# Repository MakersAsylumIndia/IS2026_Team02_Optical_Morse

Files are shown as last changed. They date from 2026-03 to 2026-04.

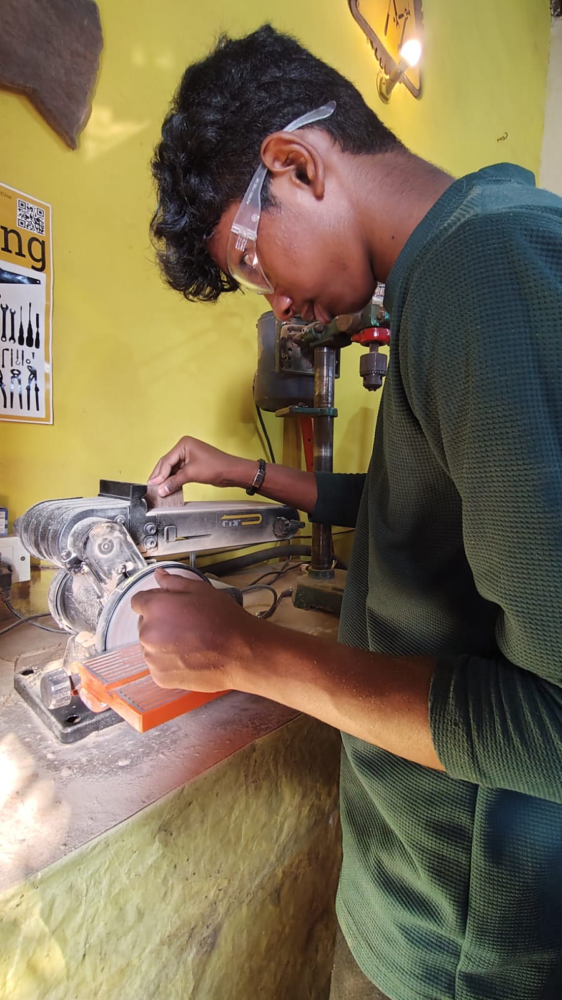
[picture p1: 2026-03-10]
Photos_Videos/Images/IS2026_Team02_Optical_Morse_photo_13.jpeg

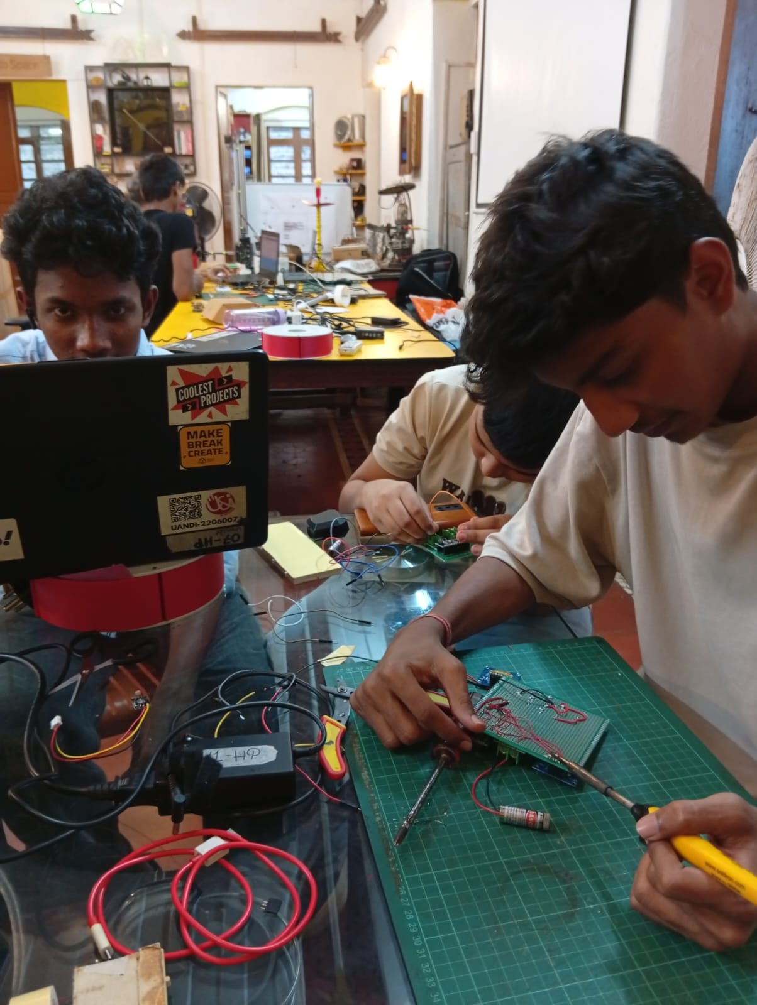
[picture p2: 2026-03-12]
Photos_Videos/Images/IS2026_Team02_Optical_Morse_photo_21.jpeg

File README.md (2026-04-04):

# IS2026 Spring - Team 02 - Optical Morse

We built a device to help communicate using simple lasers and LDR's which is not dependent on WiFi, Bluetooth or other radio technologies. We modulate a laser using morse code, which is interpreted on the receiving side using a LDR. Both sides have identical hardware - Arduino Nano for the microcontroller, a red laser, a LDR, and a mosfet module to modulate the lasers. Text is input via a serial monitor on the Arduino IDE, and on the receiving side it gets printed on the serial monitor as well. We built a simple tripod using 3d printed parts and PVC pipes to hold all the parts. For future iteration, we plan to add an I2C OLED display, some buttons and a 3d printable morse key so that the device can be used independently without attaching a laptop.

## License

Licenses

<a href="LICENSE.md">Open Source Licenses Facts</a>

#### Hardware
CERN Open Hardware License Version 2 - Strongly Reciprocal ([CERN-OHL-S-2.0](https://spdx.org/licenses/CERN-OHL-S-2.0.html)).

#### Software
MIT open source [license](http://opensource.org/licenses/MIT).

#### Documentation:
<br />This work is licensed under a <a rel="license" href="http://creativecommons.org/licenses/by/4.0/">Creative Commons Attribution 4.0 International License</a>.

---
## [OSHWA Certification](https://certification.oshwa.org/list.html)

[OSHW] IN000086 | Certified open source hardware | oshwa.org/cert



---

## 📬 Contact/Team

> _List team members and contact emails or GitHub profiles._<br/>
> [Maker's Asylum](https://github.com/makersasylum)<br/>
> [@anool](https://github.com/Anool)<br/>
> [Aaditya Borhade](https://github.com/Aadityaborhade09)<br/>
> [Afiya](https://github.com/Afiya-gpj)<br/>
> [Prince Kushwaha](https://github.com/PrinceKushwaha09)<br/>
> [suzmak8-cloud](https://github.com/suzmak8-cloud)<br/>
> [Swadhin Kumar Bhoi](https://github.com/swadhinkumarbhoi3-a11y)<br/>
> [Dakshat](https://github.com/dakshatt)<br/>
>
> ---

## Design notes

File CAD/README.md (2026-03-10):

This folder will contain all of your mechanical designs/CAD files.

push test

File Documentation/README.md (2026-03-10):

This folder will contain all of your documentation which includes details of project /instructions/flow diagram files.

testing

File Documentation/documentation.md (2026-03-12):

Optical Morse Communication Project

1\. Introduction

The Optical Morse project is a communication system that sends messages using light signals. In this project, a laser is used as a transmitter and an LDR sensor is used as a receiver. The laser sends Morse code signals, and the receiver detects the light and converts it into readable signals.

2\. Required Components

Arduino Nano

MOSFET module

Laser module

LDR (Light Dependent Resistor)

10k Resistor

Breadboard

Jumper wires

USB cable

3\. Required Components

Laser Transmitter Connection (using MOSFET Module)

Connect Arduino D9 → IN pin of the MOSFET module.

Connect Arduino GND → GND pin of the MOSFET module.

Connect 5V from Arduino → V+ of the MOSFET module.

Connect Arduino GND → V− of the MOSFET module.

Connect Laser positive (+) → OUT+.

Connect Laser negative (−) → OUT−.

LDR Receiver Connection

One leg of LDR → 5V

Other leg of LDR → A0

From the same A0 point → 10k resistor → GND

This forms the voltage divider needed for reading light.

4\. Working Principle (Optical Morse):

The Optical Morse project works on the principle of light-based communication. A laser is used to transmit signals in the form of Morse code (dots and dashes). The Arduino Nano controls the laser through the MOSFET module and turns it on and off to send the message.

At the receiver side, an LDR (Light Dependent Resistor) detects the laser light. When the laser light falls on the LDR, its resistance changes and the Arduino reads this change as a signal. The Arduino then processes these signals to determine whether the message has been received.

5\. Demonstration

Transmitter Side:

At the transmitter side, the Arduino Nano controls the laser module through the MOSFET module. When the code runs, the Arduino turns the laser on and off to send Morse code signals. These light signals represent the message being transmitted.

Receiver Side:

At the receiver side, the LDR sensor detects the laser light sent by the transmitter. When the light falls on the LDR, its resistance changes and the Arduino reads the signal through the analog pin. This confirms that the 

message sent from the transmitter has been successfully received.

6\. code

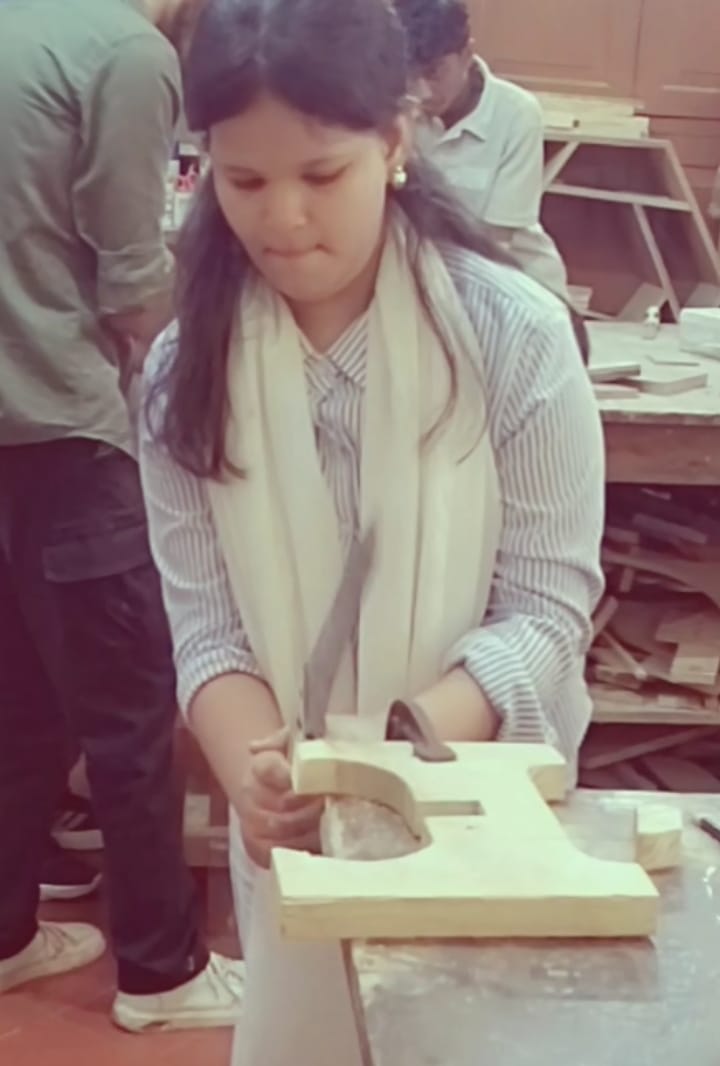
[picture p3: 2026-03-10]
Photos_Videos/Images/IS2026_Team02_Optical_Morse_photo_04.jpeg

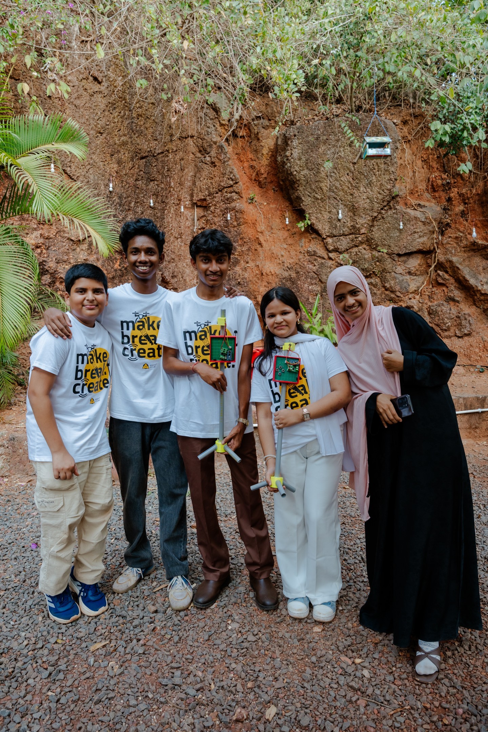
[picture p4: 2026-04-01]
Photos_Videos/Images/IS2026_Team02_Optical_Morse_photo_24.jpg

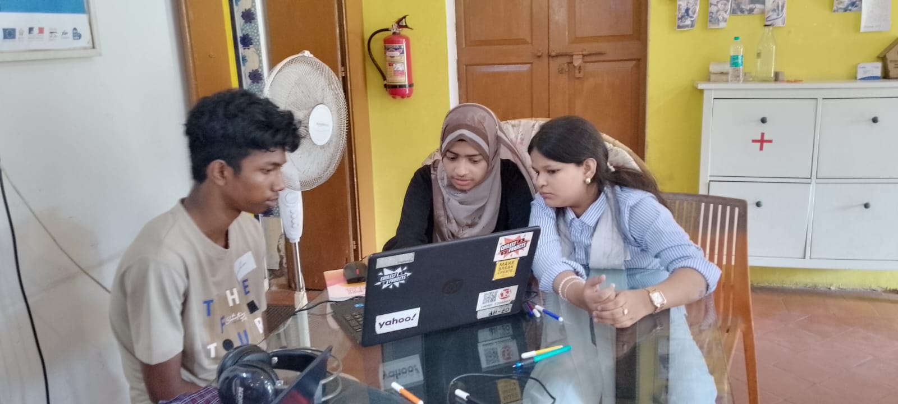
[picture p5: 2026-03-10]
Photos_Videos/Images/IS2026_Team02_Optical_Morse_photo_08.jpeg

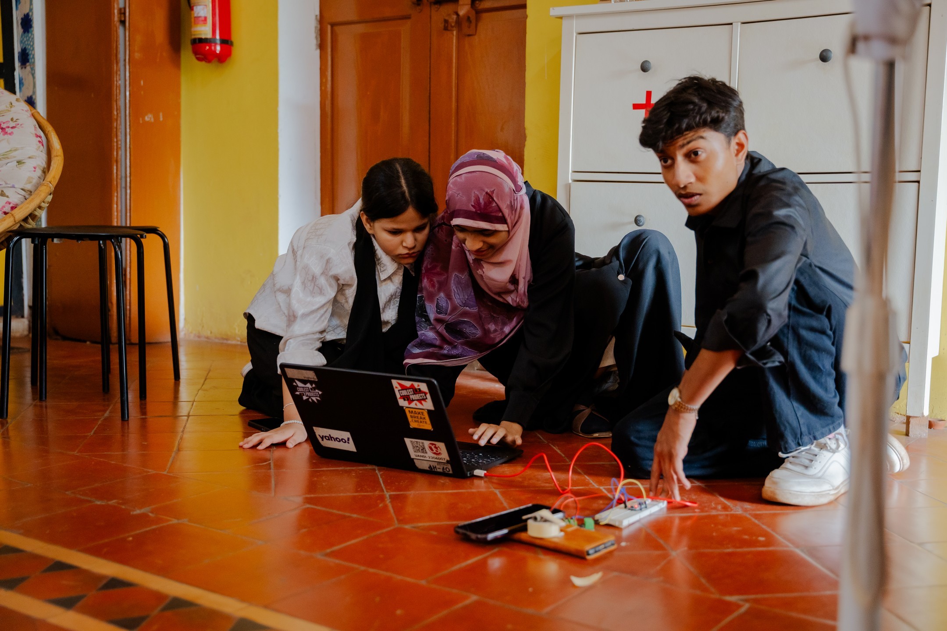
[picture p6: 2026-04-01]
Photos_Videos/Images/IS2026_Team02_Optical_Morse_photo_25.jpg

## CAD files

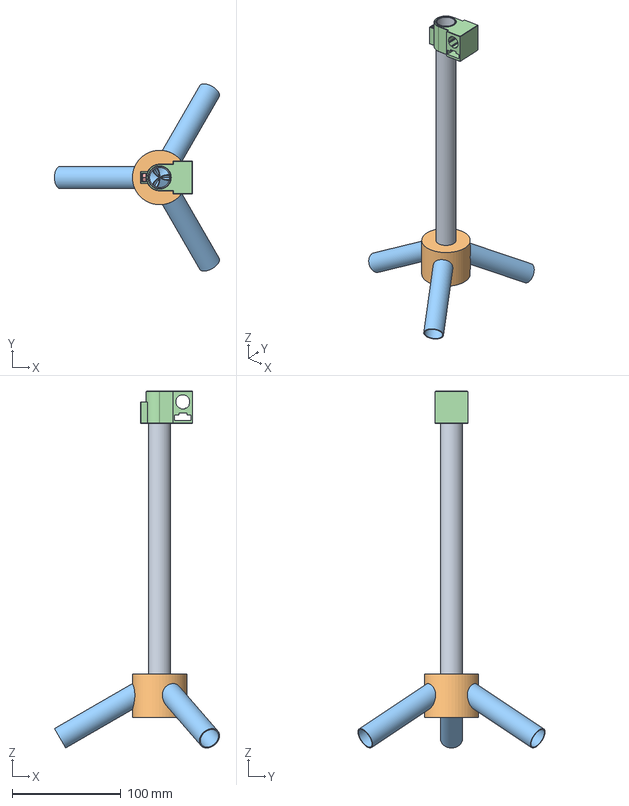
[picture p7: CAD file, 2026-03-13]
CAD/CAD_final_files/tripod_stand.FCStd
151.6 x 172.0 x 327.8 mm
main_pipe
lower_support
lower_pipes
laser_holder
M4-Nut

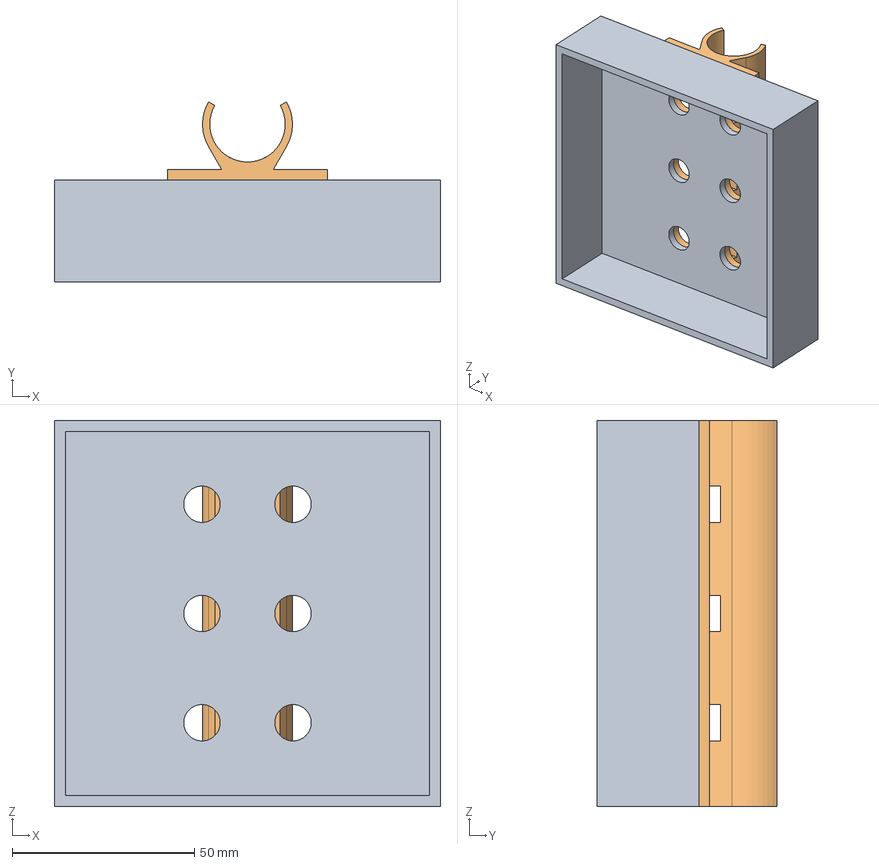
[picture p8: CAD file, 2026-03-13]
CAD/CAD_final_files/enclosure.FCStd
106.0 x 49.5 x 106.0 mm
enclosure
clip

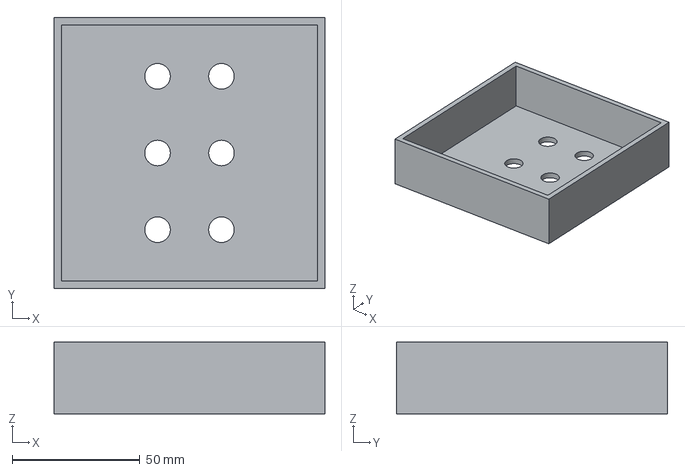
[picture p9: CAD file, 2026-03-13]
CAD/CAD_final_files/enclosure-enclosure.step
106.0 x 106.0 x 28.0 mm

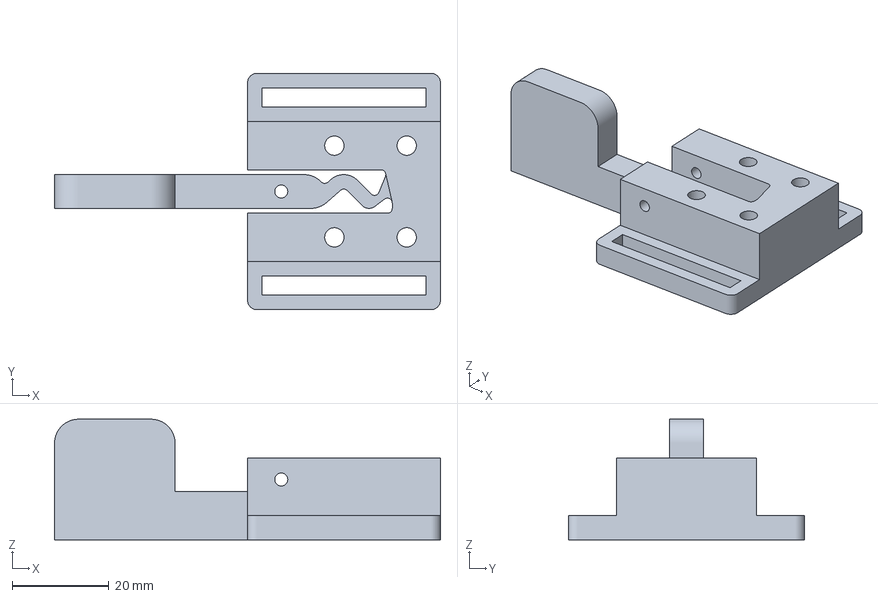
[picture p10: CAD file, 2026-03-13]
CAD/CAD_final_files/CW_paddle_Adivor_V2.3mf
80.0 x 49.0 x 25.0 mm

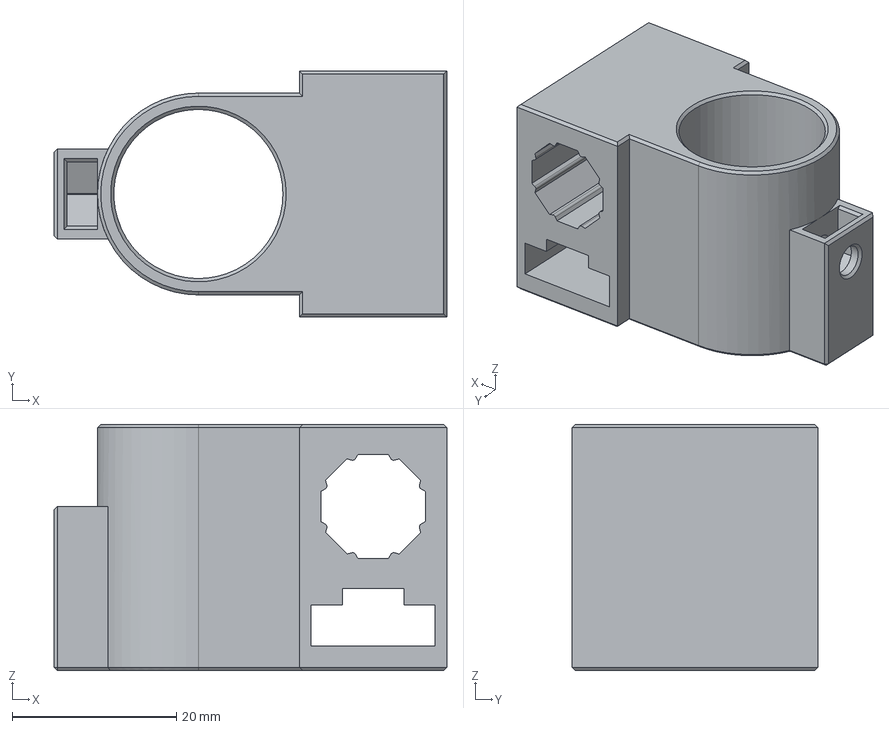
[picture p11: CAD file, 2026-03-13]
CAD/CAD_final_files/tripod_stand-laser_holder.step
47.9 x 30.0 x 30.0 mm

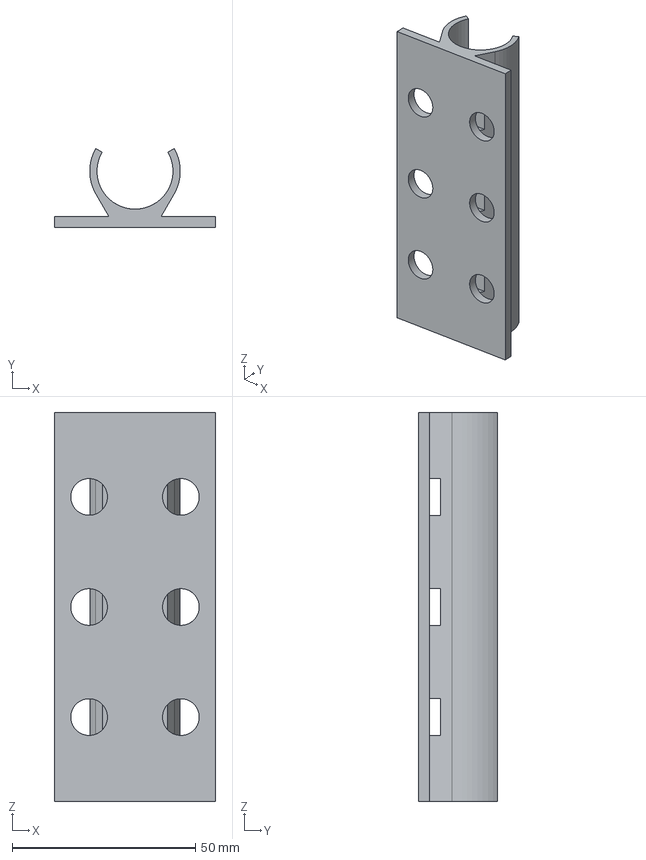
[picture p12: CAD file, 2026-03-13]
CAD/CAD_final_files/enclosure-clip.step
44.0 x 21.5 x 106.0 mm

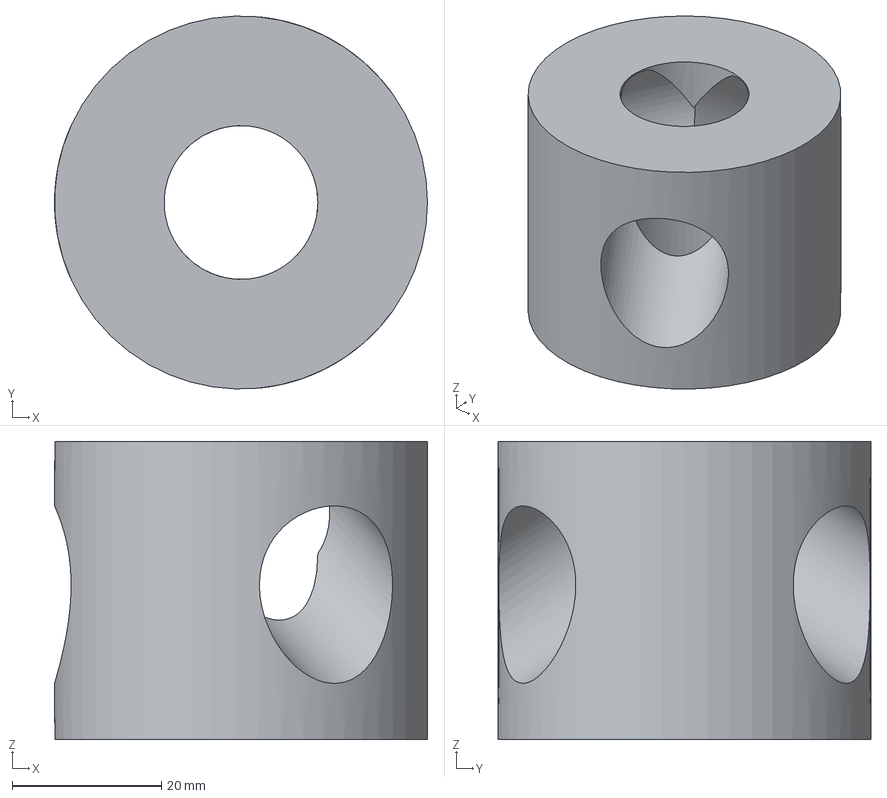
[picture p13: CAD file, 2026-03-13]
CAD/CAD_final_files/tripod_stand-lower_support.step
50.0 x 50.0 x 40.0 mm

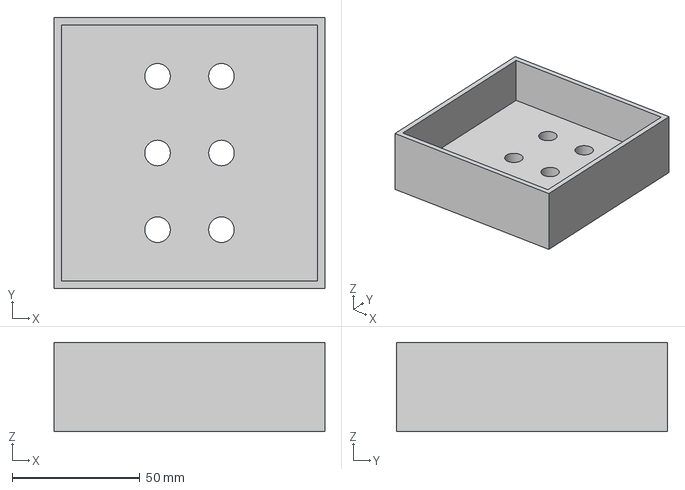
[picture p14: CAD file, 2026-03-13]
CAD/CAD_final_files/MORSE2.step
106.0 x 106.0 x 35.0 mm

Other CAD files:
CAD/CAD_final_files/MORSE2.gcode.3mf
CAD/CAD_final_files/MORSE2.3mf
CAD/CAD_final_files/enclosure-enclosure.3mf
CAD/CAD_final_files/tripod_stand-lower_support.3mf
CAD/MORSE2.f3d

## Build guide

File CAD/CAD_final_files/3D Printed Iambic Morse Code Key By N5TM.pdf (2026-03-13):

## 3D Printed Iambic Morse Code Key By N5TM

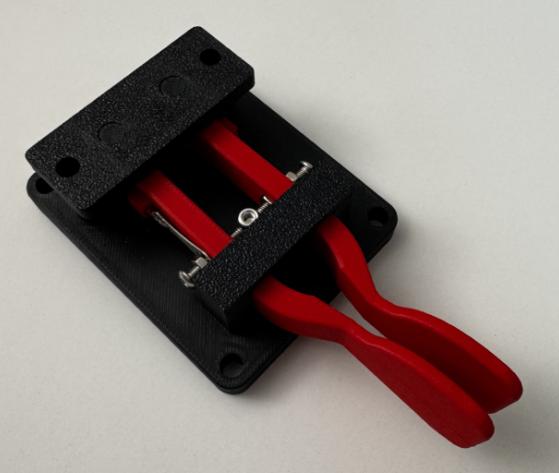
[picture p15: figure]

1) Press the magnets into the base

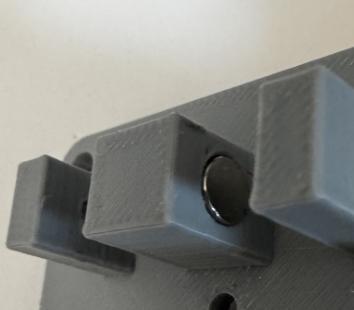
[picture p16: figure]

I like to align them with a pair of pliers then use one of the paddles handles to press into the plastic hole. Position them N-S N-S so that they attract each other.

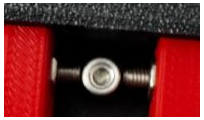
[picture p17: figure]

2) Install the center post in the base.

3) Press the magnets into the paddles.

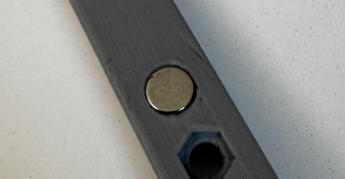
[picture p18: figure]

Make sure that the magnets will be in opposing directions from the magnets in the Base. I like to put one of them close to the corresponding magnet in the base which will grab it. Then very carefully use pliers to slide it off of the base magnet, maintaining the correct N-S direction.
Turn the magnet over before pressing into the paddle, to align for opposing forces. Test for opposing polarization by temporarily sliding the paddle into place.
4) Solder wires onto each of the lugs provided. One for the underside of the center post, and two for each paddle.

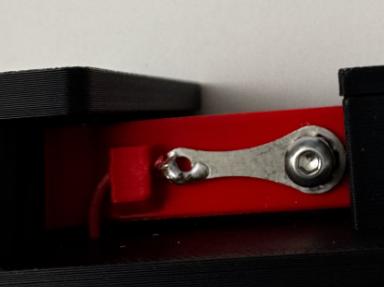
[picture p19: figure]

Slide the wire through the hole in the paddle. Then install the M3 hex screws and nuts.

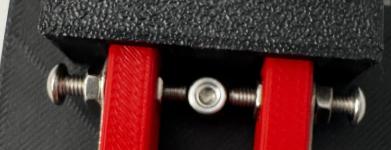
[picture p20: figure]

5) Slide the paddles onto the posts and test the alignment.
You can adjust the spacing of the M3 screws to your preference with the center post.
6) Thread the wire from each paddle through the holes in the base.

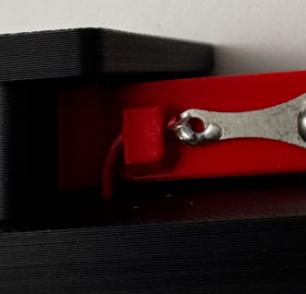
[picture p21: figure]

7) On the bottom side place the wire into the slots and connect to the 6-32 screws.

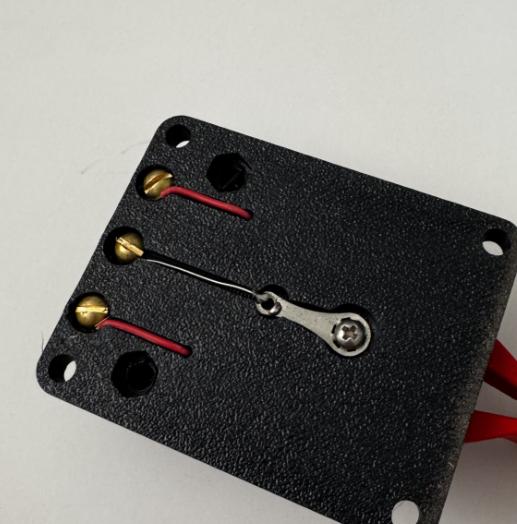
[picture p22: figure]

I just strip a portion of the wire and wrap it around the screw, then tighten the nut on the top side.
8) I suggest mounting the key to a board or heavy piece of metal.
Attach Dit -Dah wires to each of the outer screw posts and the common (Gnd) wire to the center post.

9) Kit Contents

### 1. Key base 2. Left paddle 3. Right paddle 4. Front hold down bracket 5. Rear hold down bracket 6. Rare earth 6X2mm magnets (4 pieces) 7. M3 screws (2 pieces) 8. M3 nuts (4 pieces) 9. Center post and 14/20 screw 10. Solder terminals (3 pieces)

11. 6-32 screws and nuts (3 sets)

### 12. Solder and wire not included

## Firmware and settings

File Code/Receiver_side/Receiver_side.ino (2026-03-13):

// -------------------- Optical Morse: Send + Receive --------------------
int laserPin = 9;   // Laser via MOSFET
int ldrPin = A0;    // 3-pin LDR module signal pin

int dotTime = 200;       // Duration of dot
int threshold = 500;     // LDR module threshold

bool laserOn = false;
unsigned long startTime;
unsigned long lastChange;

String currentMorse = "";

// Morse code table
String morse[] = {
  ".-","-...","-.-.","-..",".","..-.","--.","....","..",".---",
  "-.-",".-..","--","-.","---",".--.","--.-",".-.","...","-",
  "..-","...-",".--","-..-","-.--","--..",
  ".----","..---","...--","....-",".....","-....","--...","---..","----.","-----",
  "--..--",".-.-.-","..--.."
};

char letters[] = {
'A','B','C','D','E','F','G','H','I','J',
'K','L','M','N','O','P','Q','R','S','T',
'U','V','W','X','Y','Z',
'1','2','3','4','5','6','7','8','9','0',
',','.','?'
};

void setup() {
  Serial.begin(9600);
  pinMode(laserPin, OUTPUT);
  digitalWrite(laserPin, HIGH);  // Laser OFF initially (MOSFET active LOW)
  Serial.println("Optical Morse Ready: Send + Receive");
}

// ---------------- Send Morse ----------------
void sendDot() {
  digitalWrite(laserPin, LOW);   // Laser ON
  delay(dotTime);
  digitalWrite(laserPin, HIGH);  // Laser OFF
  delay(dotTime);
}

void sendDash() {
  digitalWrite(laserPin, LOW);   // Laser ON
  delay(dotTime*3);
  digitalWrite(laserPin, HIGH);  // Laser OFF
  delay(dotTime);
}

void sendText(String text) {
  text.toUpperCase();
  for(int i = 0; i < text.length(); i++) {
    char c = text[i];
    for(int k = 0; k < 39; k++) {
      if(c == letters[k]) {
        String code = morse[k];
        for(int j = 0; j < code.length(); j++) {
          if(code[j] == '.') sendDot();
          else sendDash();
        }
        delay(dotTime*2); // letter spacing
      }
    }
    if(c == ' ') delay(dotTime*7); // word spacing
  }
}

// ---------------- Decode Morse ----------------
void decodeMorse(String code) {
  for(int i = 0; i < 39; i++) {
    if(code == morse[i]) {
      char letter = letters[i];
      Serial.print(letter);
      return;
    }
  }
}

// ---------------- Main Loop ----------------
void loop() {
  unsigned long currentTime = millis();

  // -------- SEND via Serial --------
  if(Serial.available()) {
    String text = Serial.readStringUntil('\n');
    sendText(text);
    Serial.println();
    delay(50);
  }

  // -------- RECEIVE via LDR Module --------
  int value = analogRead(ldrPin);

  if(value > threshold && !laserOn) {
    laserOn = true;
    startTime = currentTime;
  }

  if(value < threshold && laserOn) {
    laserOn = false;
    unsigned long duration = currentTime - startTime;
    if(duration < 300) currentMorse += ".";
    else currentMorse += "-";
    lastChange = currentTime;
  }

  // Letter gap detection
  if(!laserOn && currentMorse.length() > 0 && (currentTime - lastChange) > 400) {
    decodeMorse(currentMorse);
    currentMorse = "";
    lastChange = currentTime;
  }

  // Word gap detection
  if(!laserOn && (currentTime - lastChange) > 1500) {
    Serial.print(" ");
    lastChange = currentTime;
  }
}

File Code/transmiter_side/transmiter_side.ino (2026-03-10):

int laserPin = 9;

int dot = 200;
int dash = 600;
int symbolGap = 200;
int letterGap = 600;

String letters = "ABCDEFGHIJKLMNOPQRSTUVWXYZ1234567890";

String morse[] = {
".-","-...","-.-.","-..",".","..-.","--.","....","..",".---",
"-.-",".-..","--","-.","---",".--.","--.-",".-.","...","-",
"..-","...-",".--","-..-","-.--","--..",
".----","..---","...--","....-",".....",
"-....","--...","---..","----.","-----"
};

void sendDot(){
digitalWrite(laserPin,HIGH);
delay(dot);
digitalWrite(laserPin,LOW);
delay(symbolGap);
}

void sendDash(){
digitalWrite(laserPin,HIGH);
delay(dash);
digitalWrite(laserPin,LOW);
delay(symbolGap);
}

void setup(){
pinMode(laserPin,OUTPUT);
Serial.begin(9600);
}

void loop(){

if(Serial.available()){

String text = Serial.readStringUntil('\n');
text.toUpperCase();

for(int i=0;i<text.length();i++){

char c = text[i];

int index = letters.indexOf(c);

if(index>=0){

String code = morse[index];

for(int j=0;j<code.length();j++){

if(code[j]=='.') sendDot();
if(code[j]=='-') sendDash();

}

delay(letterGap);

}

}

}

}

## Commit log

2026-03-11 Create WhatsApp Image 2026-03-11 at 11.52.44.jpeg
    ∆ Heading: Optical morse
    ∆ Required Components:
    •Arduino Nano
    •MOSFET module
    •Laser module
    •LDR (Light Dependent Resistor)
    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
2026-03-12 circuit daigram
2026-03-12 power tools session
2026-03-12 optical morse documentation
    An Optical Morse Communication project that sends message using laser light and receives them using an LDR sensor using an Arduino Nano
2026-03-13 Create Arduino IDE.lnk
2026-03-13 final CAD files added by anool
    [CW_paddle_Adivor_V2.3mf, MOARSE2.3mf, MOARSE2.gcode.3mf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]
2026-03-17 Revise project title and enhance project description
    Updated project title and provided a detailed description of the device and its functionality.
